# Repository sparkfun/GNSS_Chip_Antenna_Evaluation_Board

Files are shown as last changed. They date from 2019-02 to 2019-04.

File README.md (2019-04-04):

SparkFun GNSS Chip Antenna Evaluation Board
===========================================================

SparkFun GNSS Chip Antenna Eval Board (https://www.sparkfun.com/products/15247)

[*SparkFun GNSS Chip Antenna Eval Board (GPS-15247)*](https://www.sparkfun.com/products/15247)

The GNSS Chip Evaluation board allows for quick testing of various chip scale GPS and GNSS antennas. Various sizes and manufacturers allow the user to see for themselves how their GPS receiver will preform with each extremely small GPS antenna.

Repository Contents
-------------------

* **/Documents** - Antenna datasheets
* **/Hardware** - Eagle files

Documentation
-------------------

* **[Hookup Guide](https://learn.sparkfun.com/tutorials/gnss-chip-antenna-hookup-guide)** - Basic hookup guide for the antenna evaluation board
* **[Three Quick Tips About Using U.FL](https://learn.sparkfun.com/tutorials/three-quick-tips-about-using-ufl)** - Quick tips regarding how to connect, protect, and disconnect U.FL connectors

License Information
-------------------

This product is _**open source**_! 

Various bits of the code have different licenses applied. Anything SparkFun wrote is beerware; if you see me (or any other SparkFun employee) at the local, and you've found our code helpful, please buy us a round!

Please use, reuse, and modify these files as you see fit. Please maintain attribution to SparkFun Electronics and release anything derivative under the same license.

Distributed as-is; no warranty is given.

- Your friends at SparkFun.

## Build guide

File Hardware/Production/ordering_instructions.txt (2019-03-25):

panel size, 75x158mm
PCB thickness, 0.8mm
number of layers, 2
soldermask color, Red
silkscreen color, White
oz copper, 1oz
finish, HASL lead free
stencils, top+bottom
pcs per panel, 4

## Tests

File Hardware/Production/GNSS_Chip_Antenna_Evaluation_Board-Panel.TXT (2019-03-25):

%
M48
M72
T01C0.0120
T02C0.0400
T03C0.1300
%
T01
X6834Y9675
X6684Y13375
X7134Y13375
X7134Y14075
X7134Y14725
X6684Y14725
X5684Y14775
X5684Y13375
X7634Y13375
X8184Y13375
X8184Y14075
X7634Y14075
X7634Y14725
X8184Y14725
X8734Y14725
X8734Y15325
X8734Y15775
X8734Y16175
X8734Y16675
X9234Y16675
X9234Y16175
X9234Y15775
X9234Y15325
X8734Y14075
X8734Y13375
X10034Y17875
X10534Y17725
X10034Y18425
X10034Y18875
X9834Y19375
X10534Y19125
X10634Y19425
X11434Y19425
X11484Y19125
X12034Y18875
X12034Y18425
X12034Y17875
X11534Y17725
X13834Y23875
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

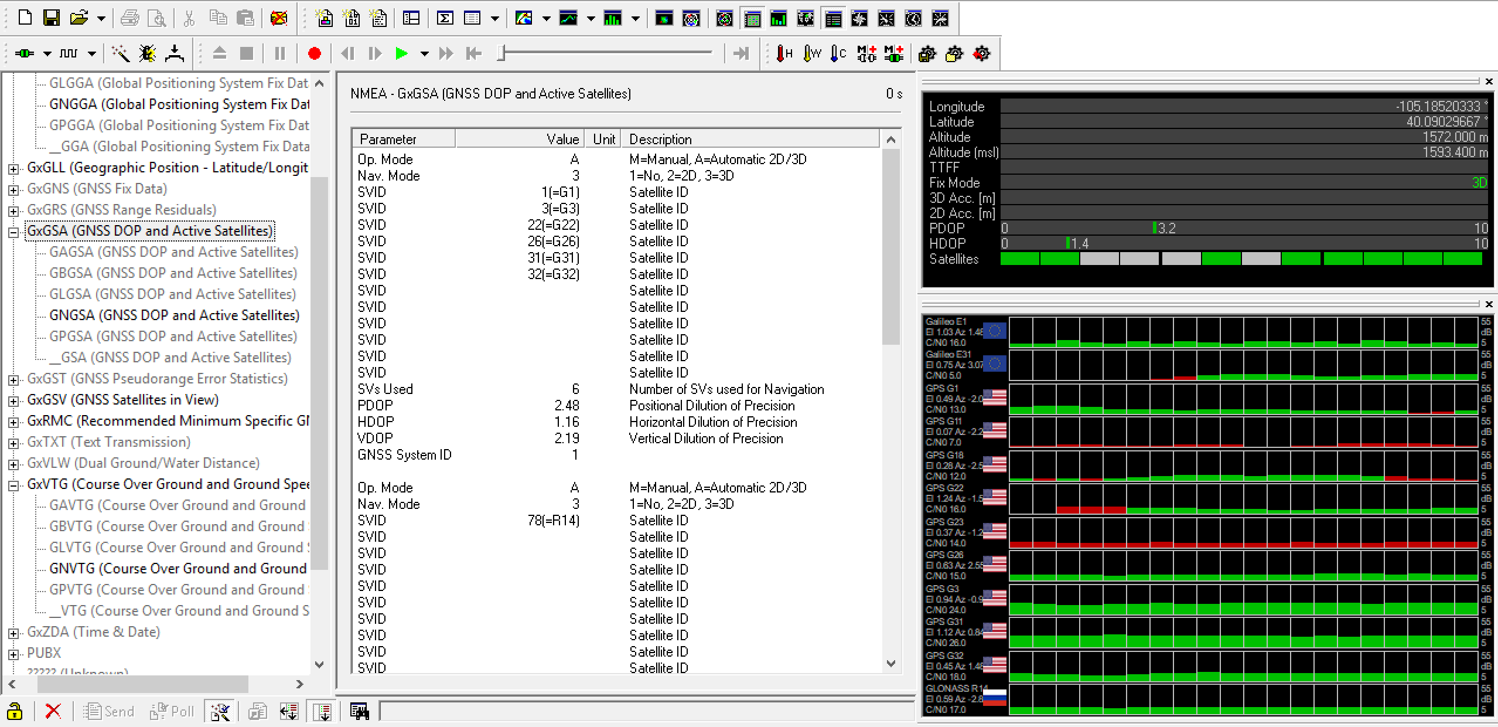
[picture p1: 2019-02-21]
Testing/W3062A.png

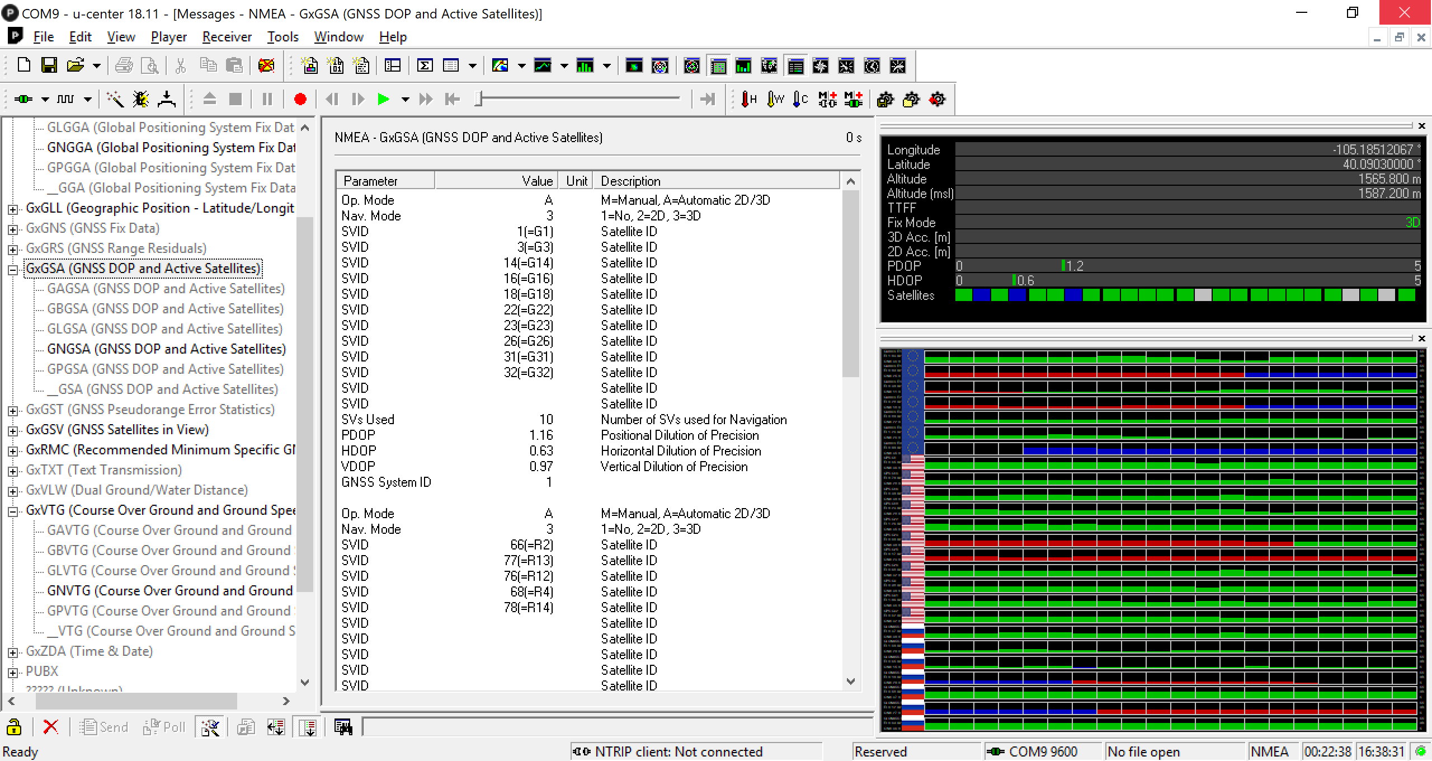
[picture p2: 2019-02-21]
Testing/Molex Cube.png

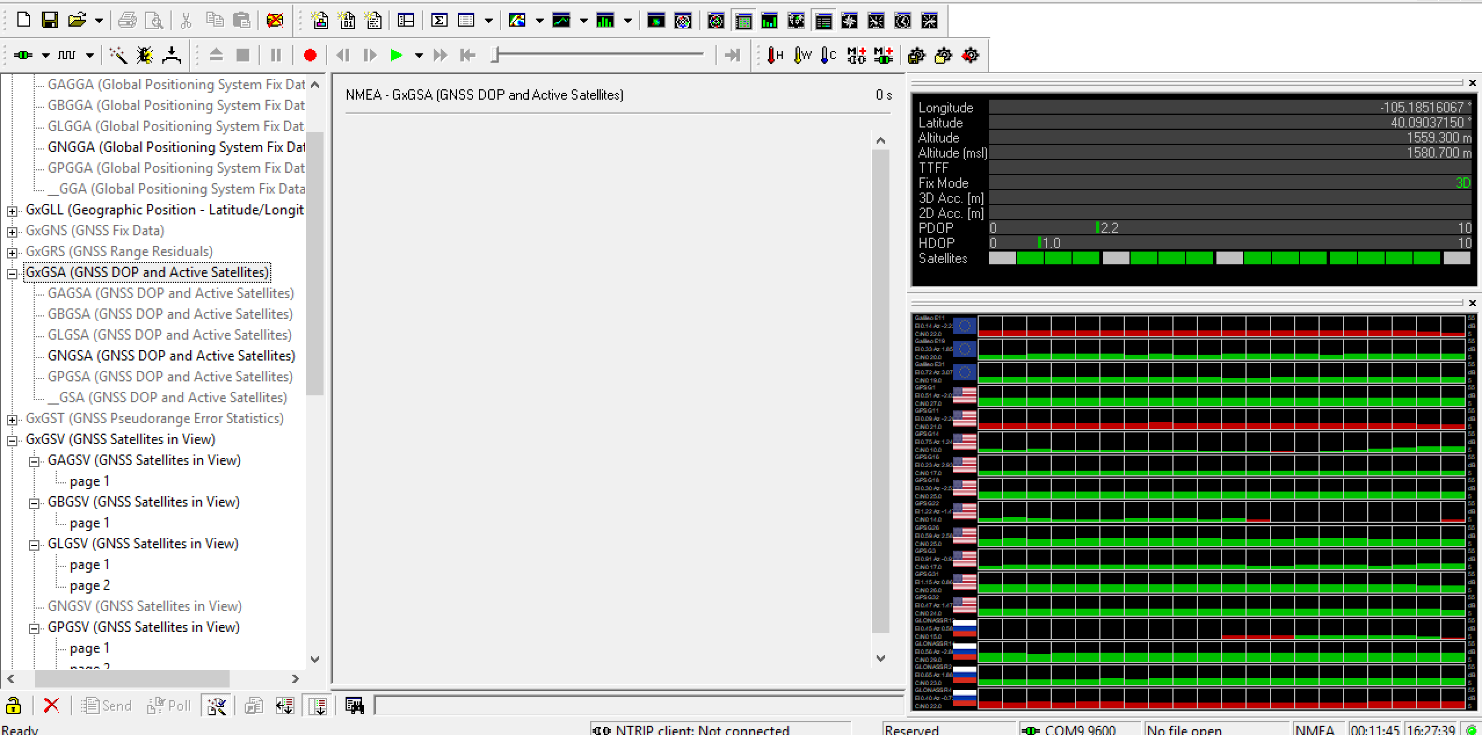
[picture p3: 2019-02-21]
Testing/Molex Molded.png

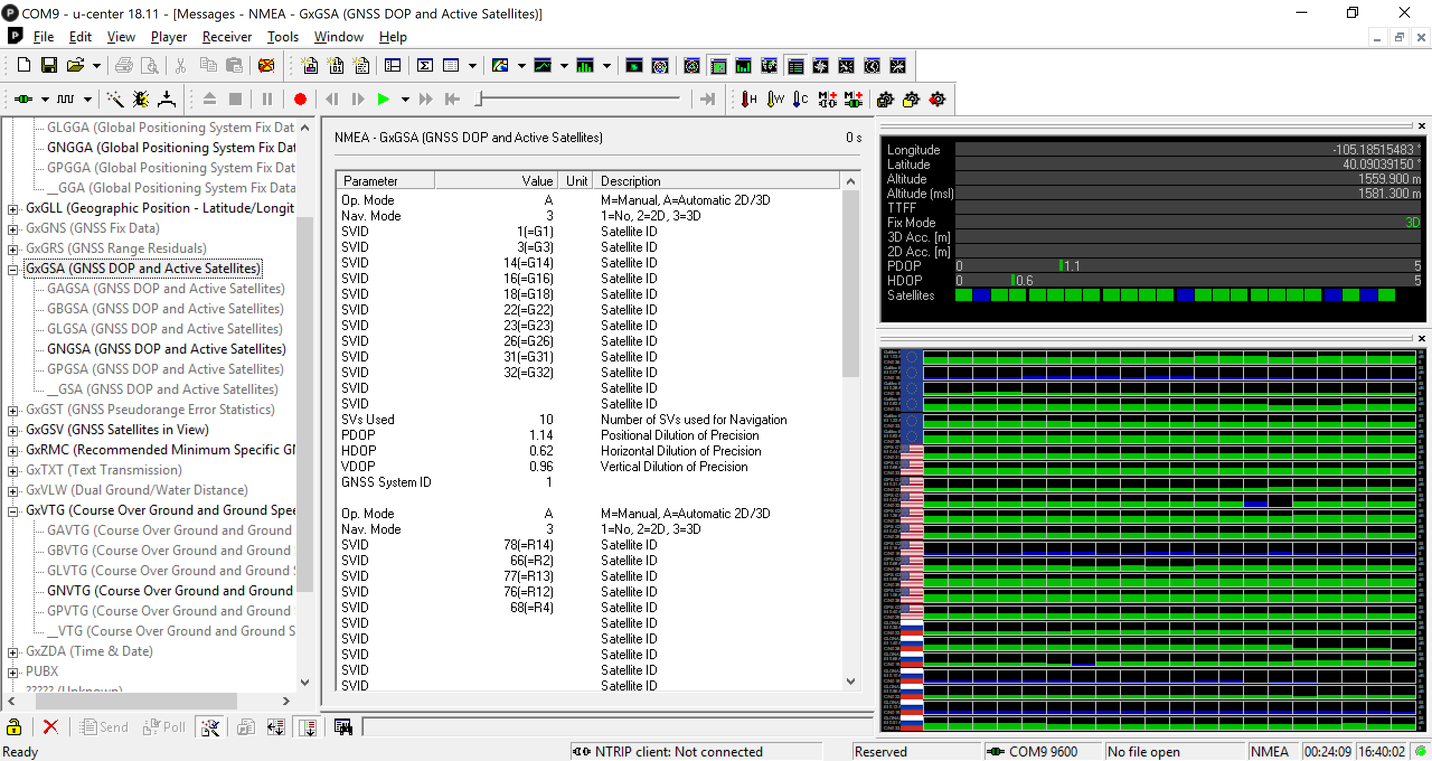
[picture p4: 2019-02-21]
Testing/Adhesive Ant.png

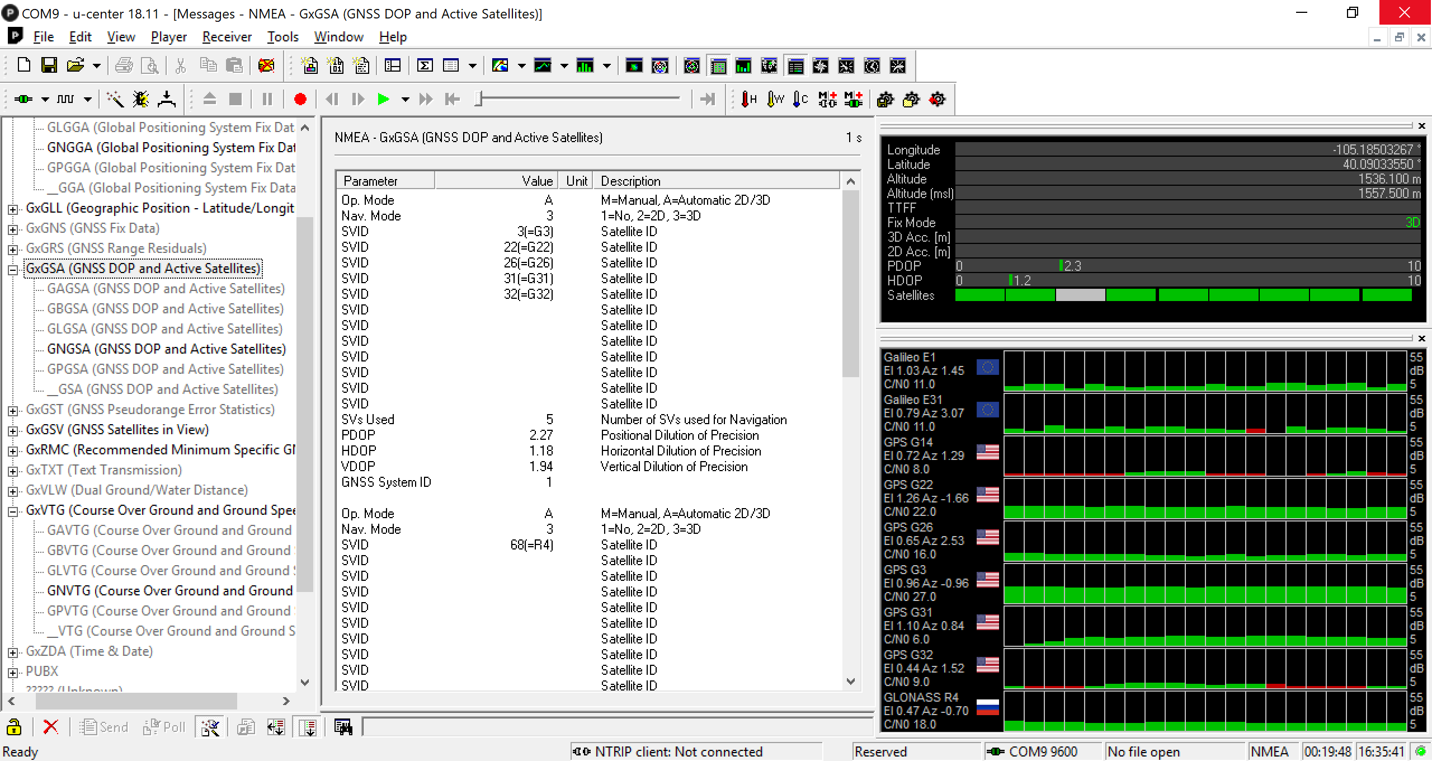
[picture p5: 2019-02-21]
Testing/Molex Chip.png

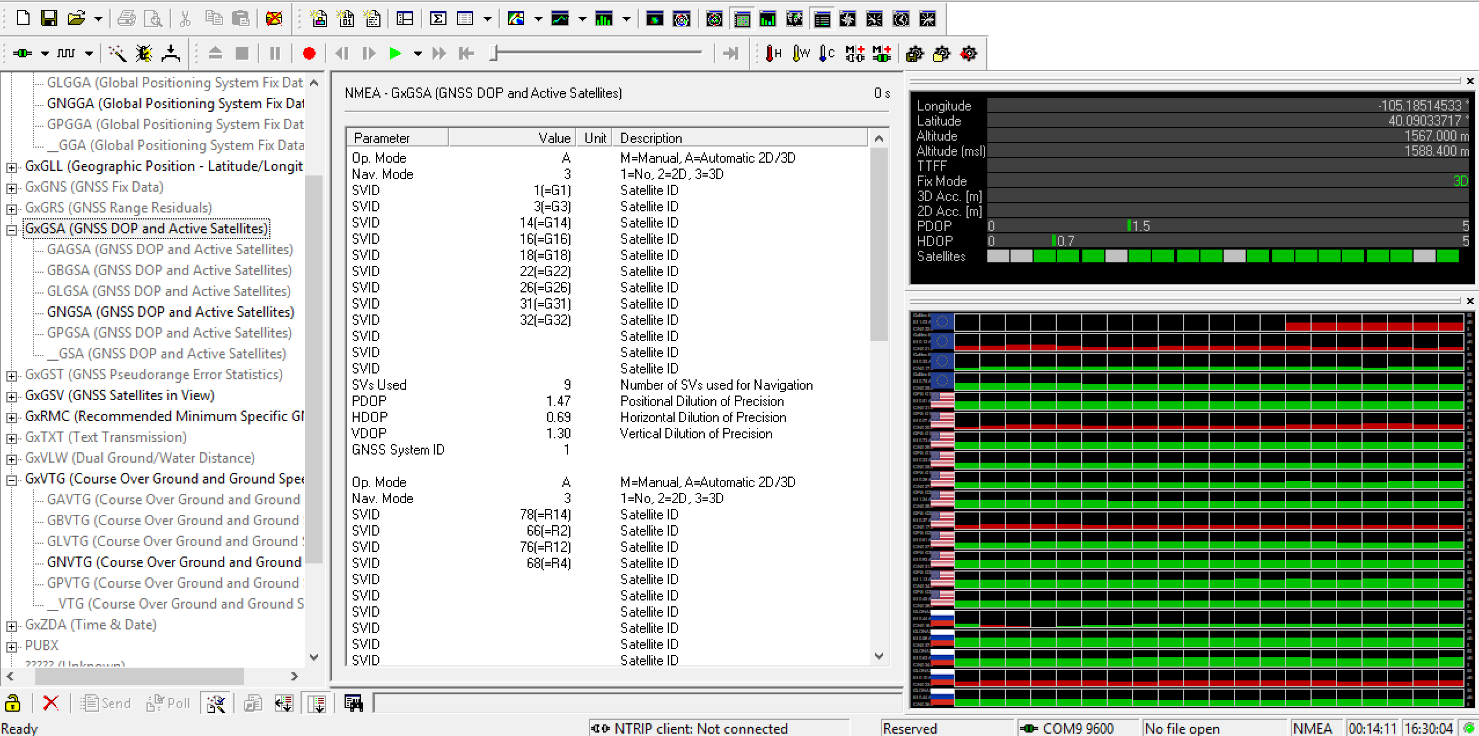
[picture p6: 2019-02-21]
Testing/W3011.png

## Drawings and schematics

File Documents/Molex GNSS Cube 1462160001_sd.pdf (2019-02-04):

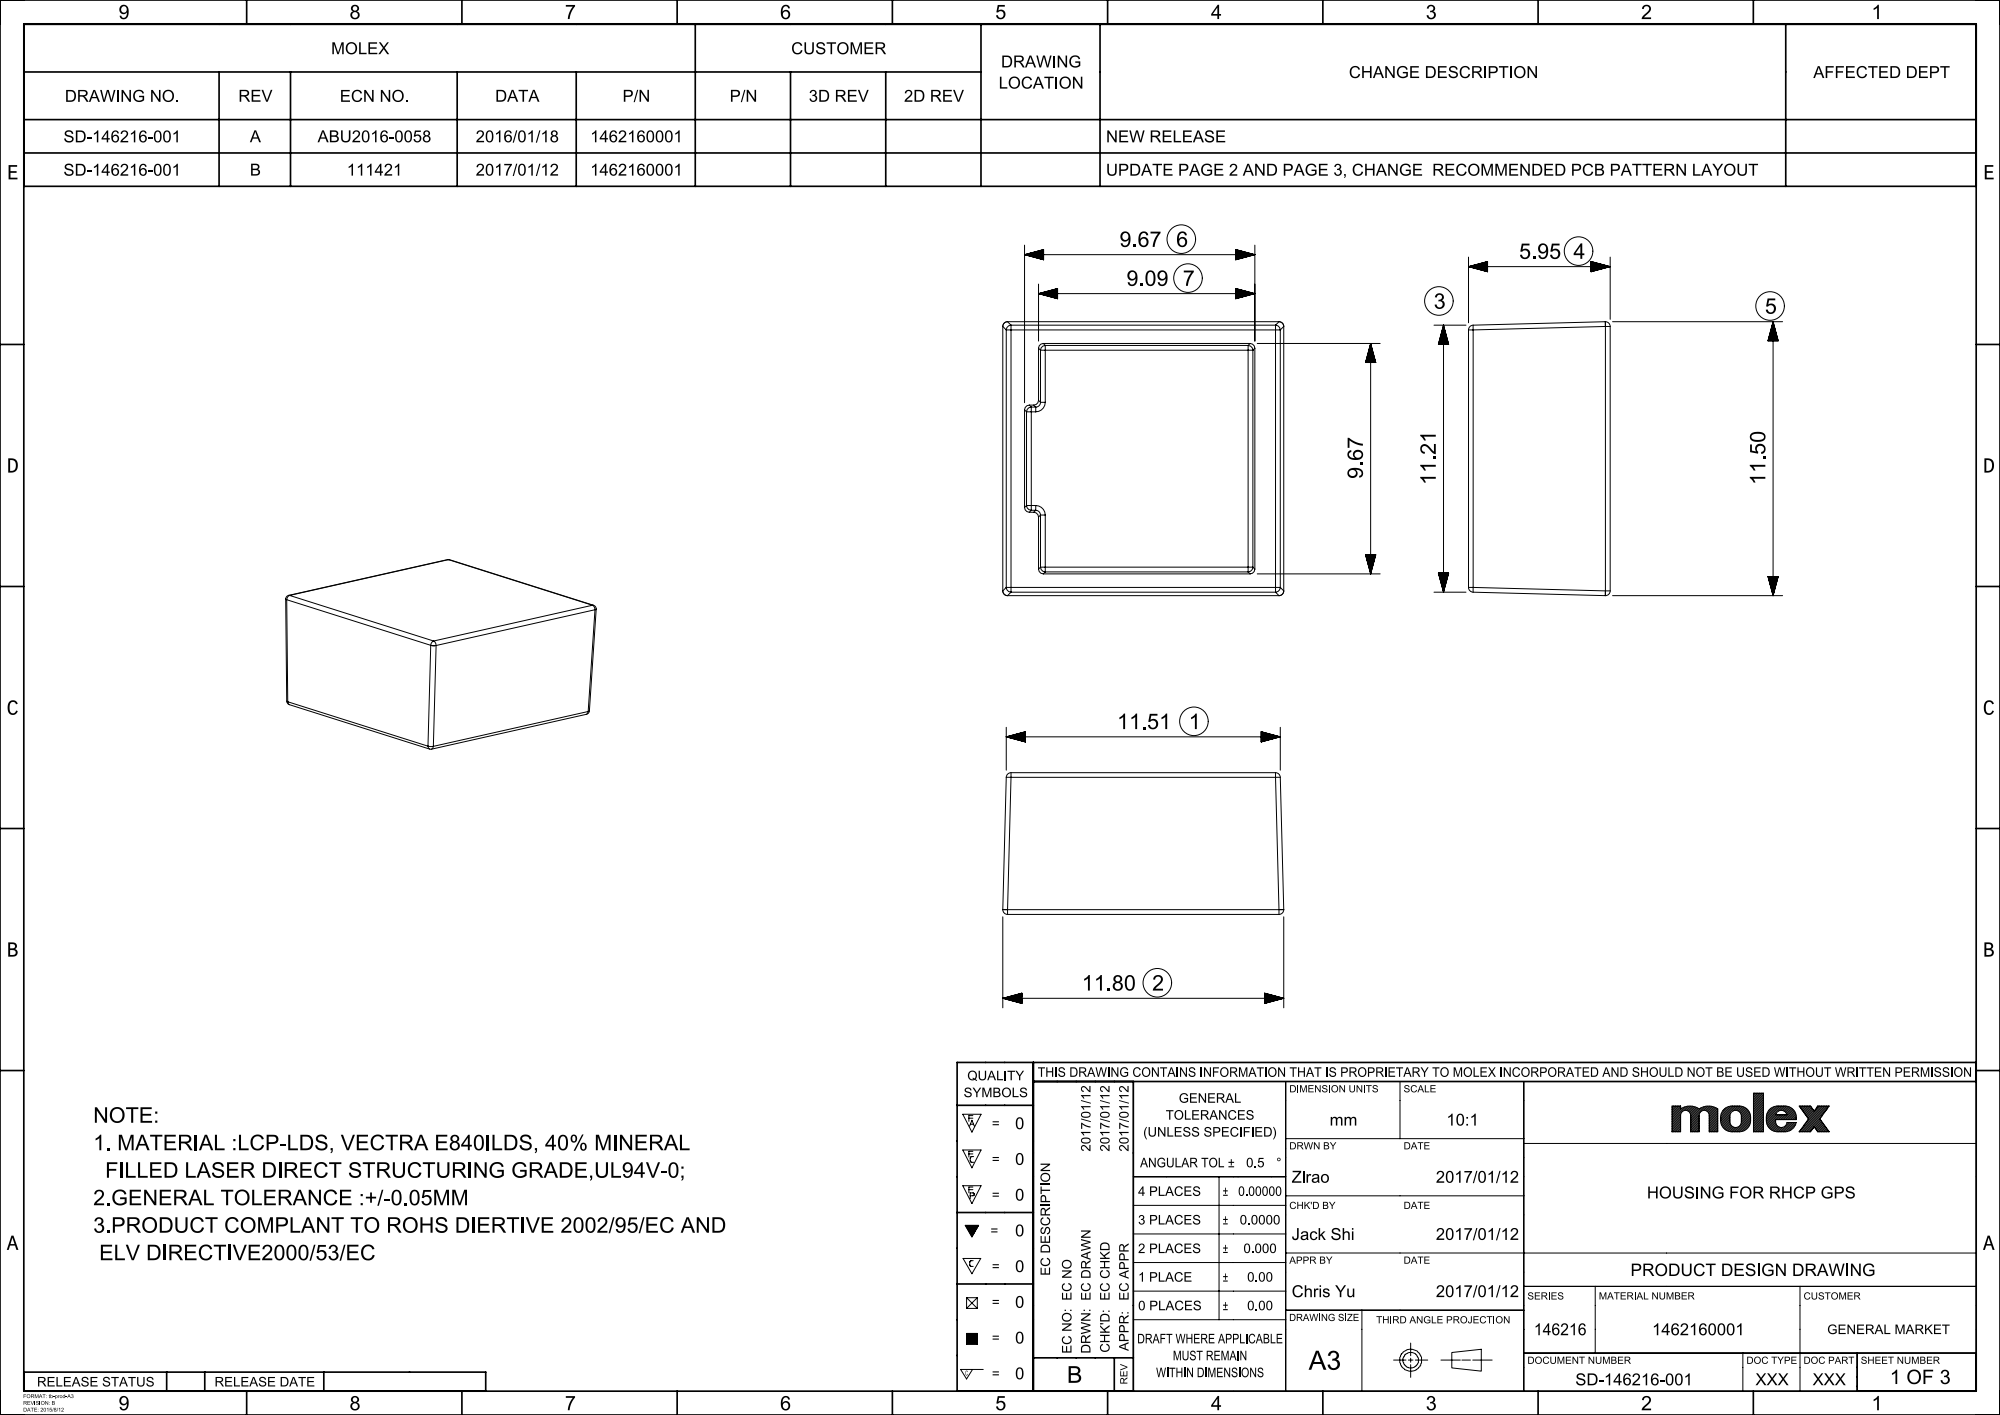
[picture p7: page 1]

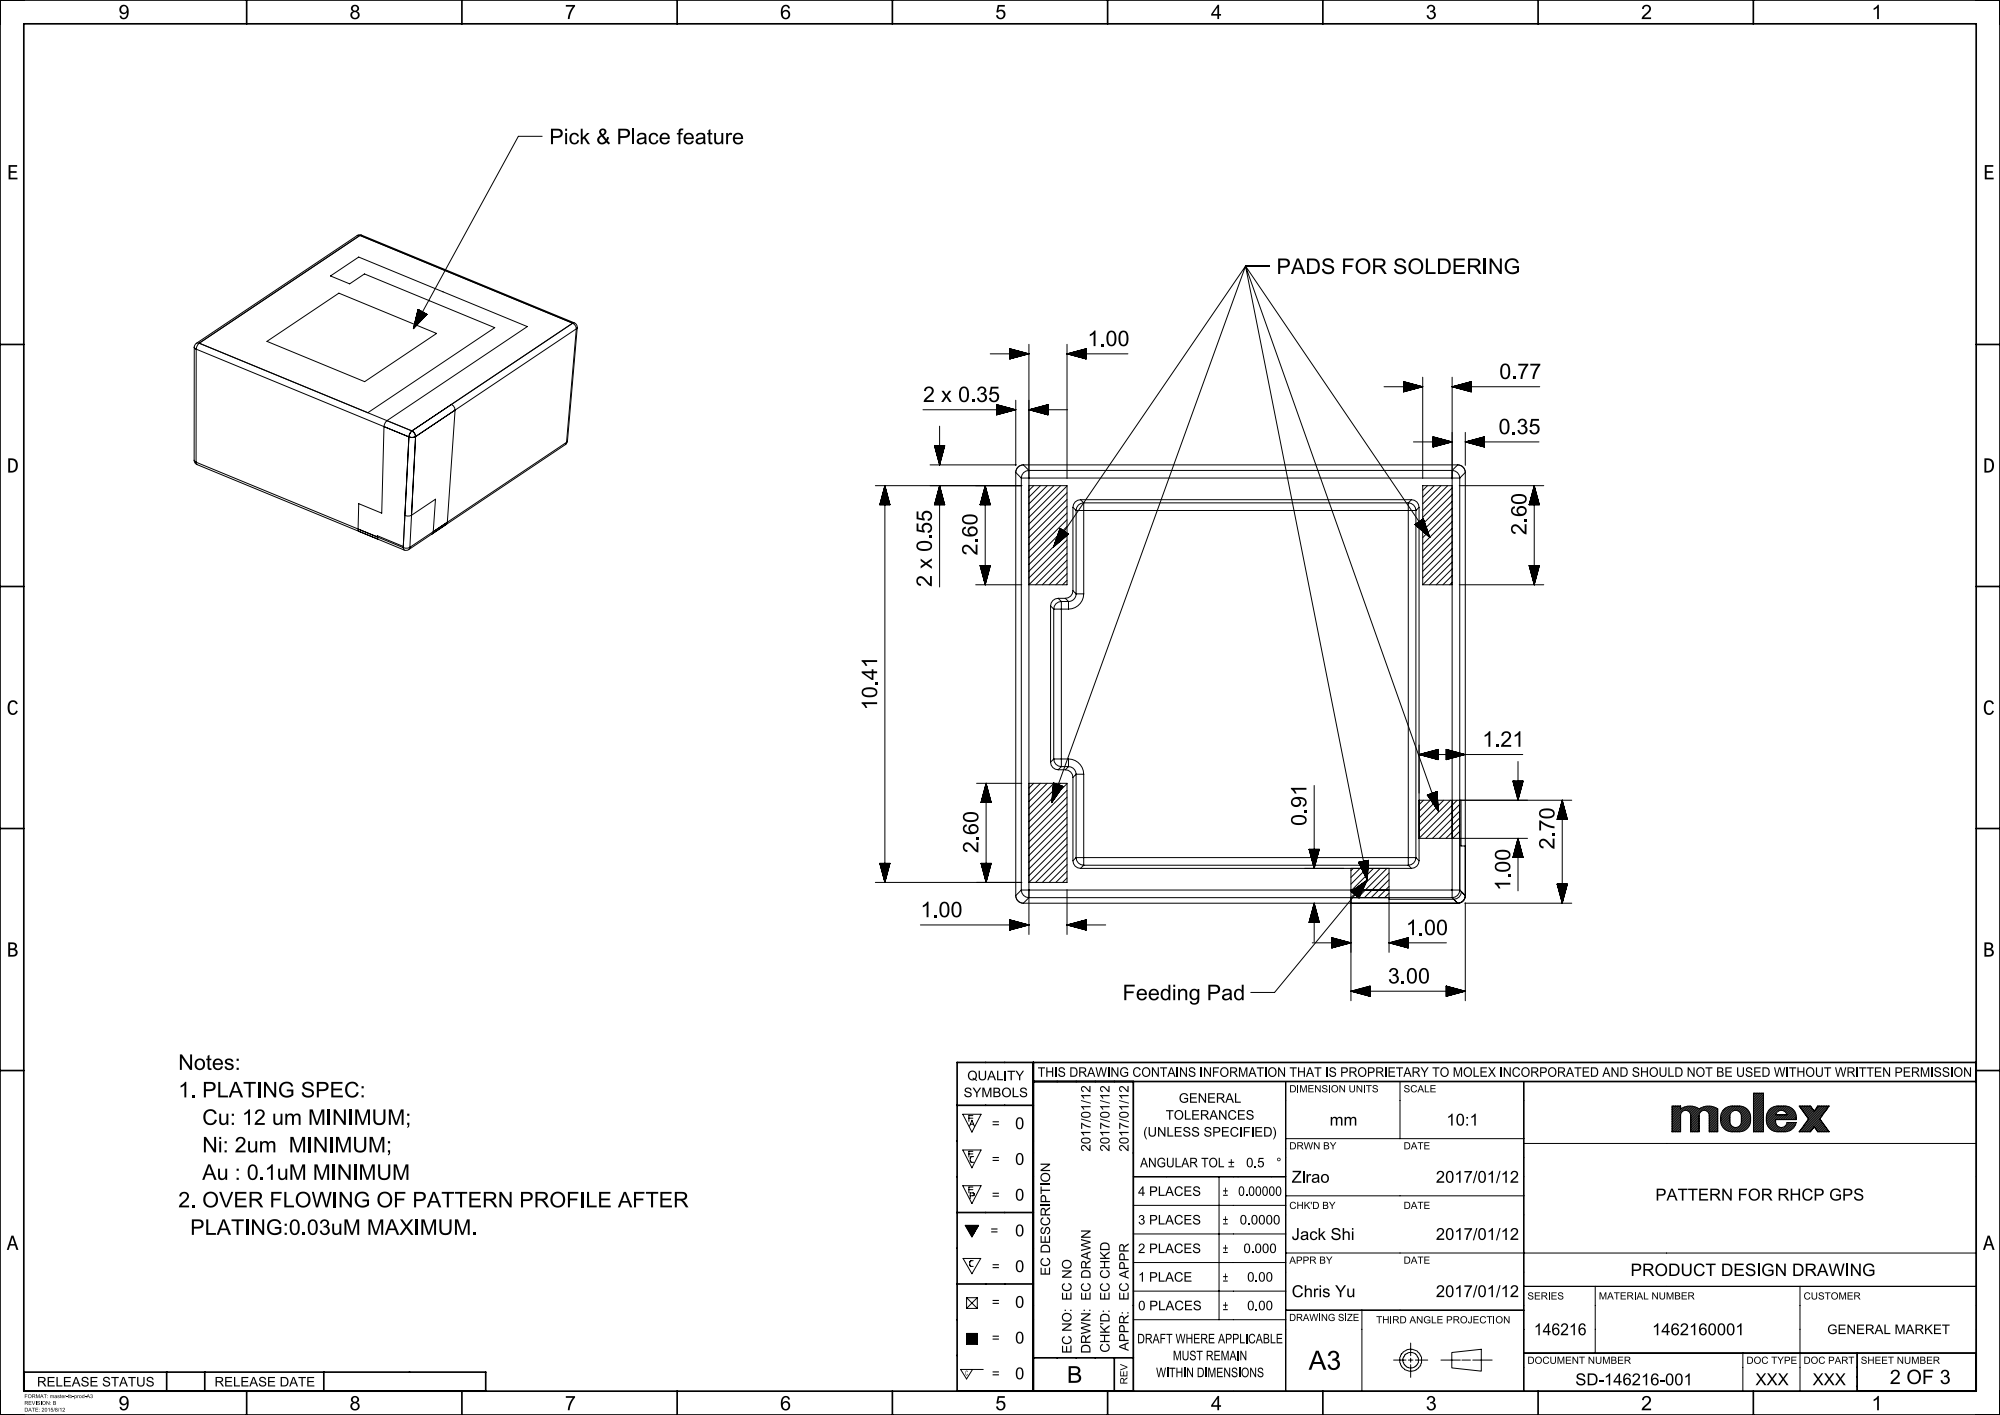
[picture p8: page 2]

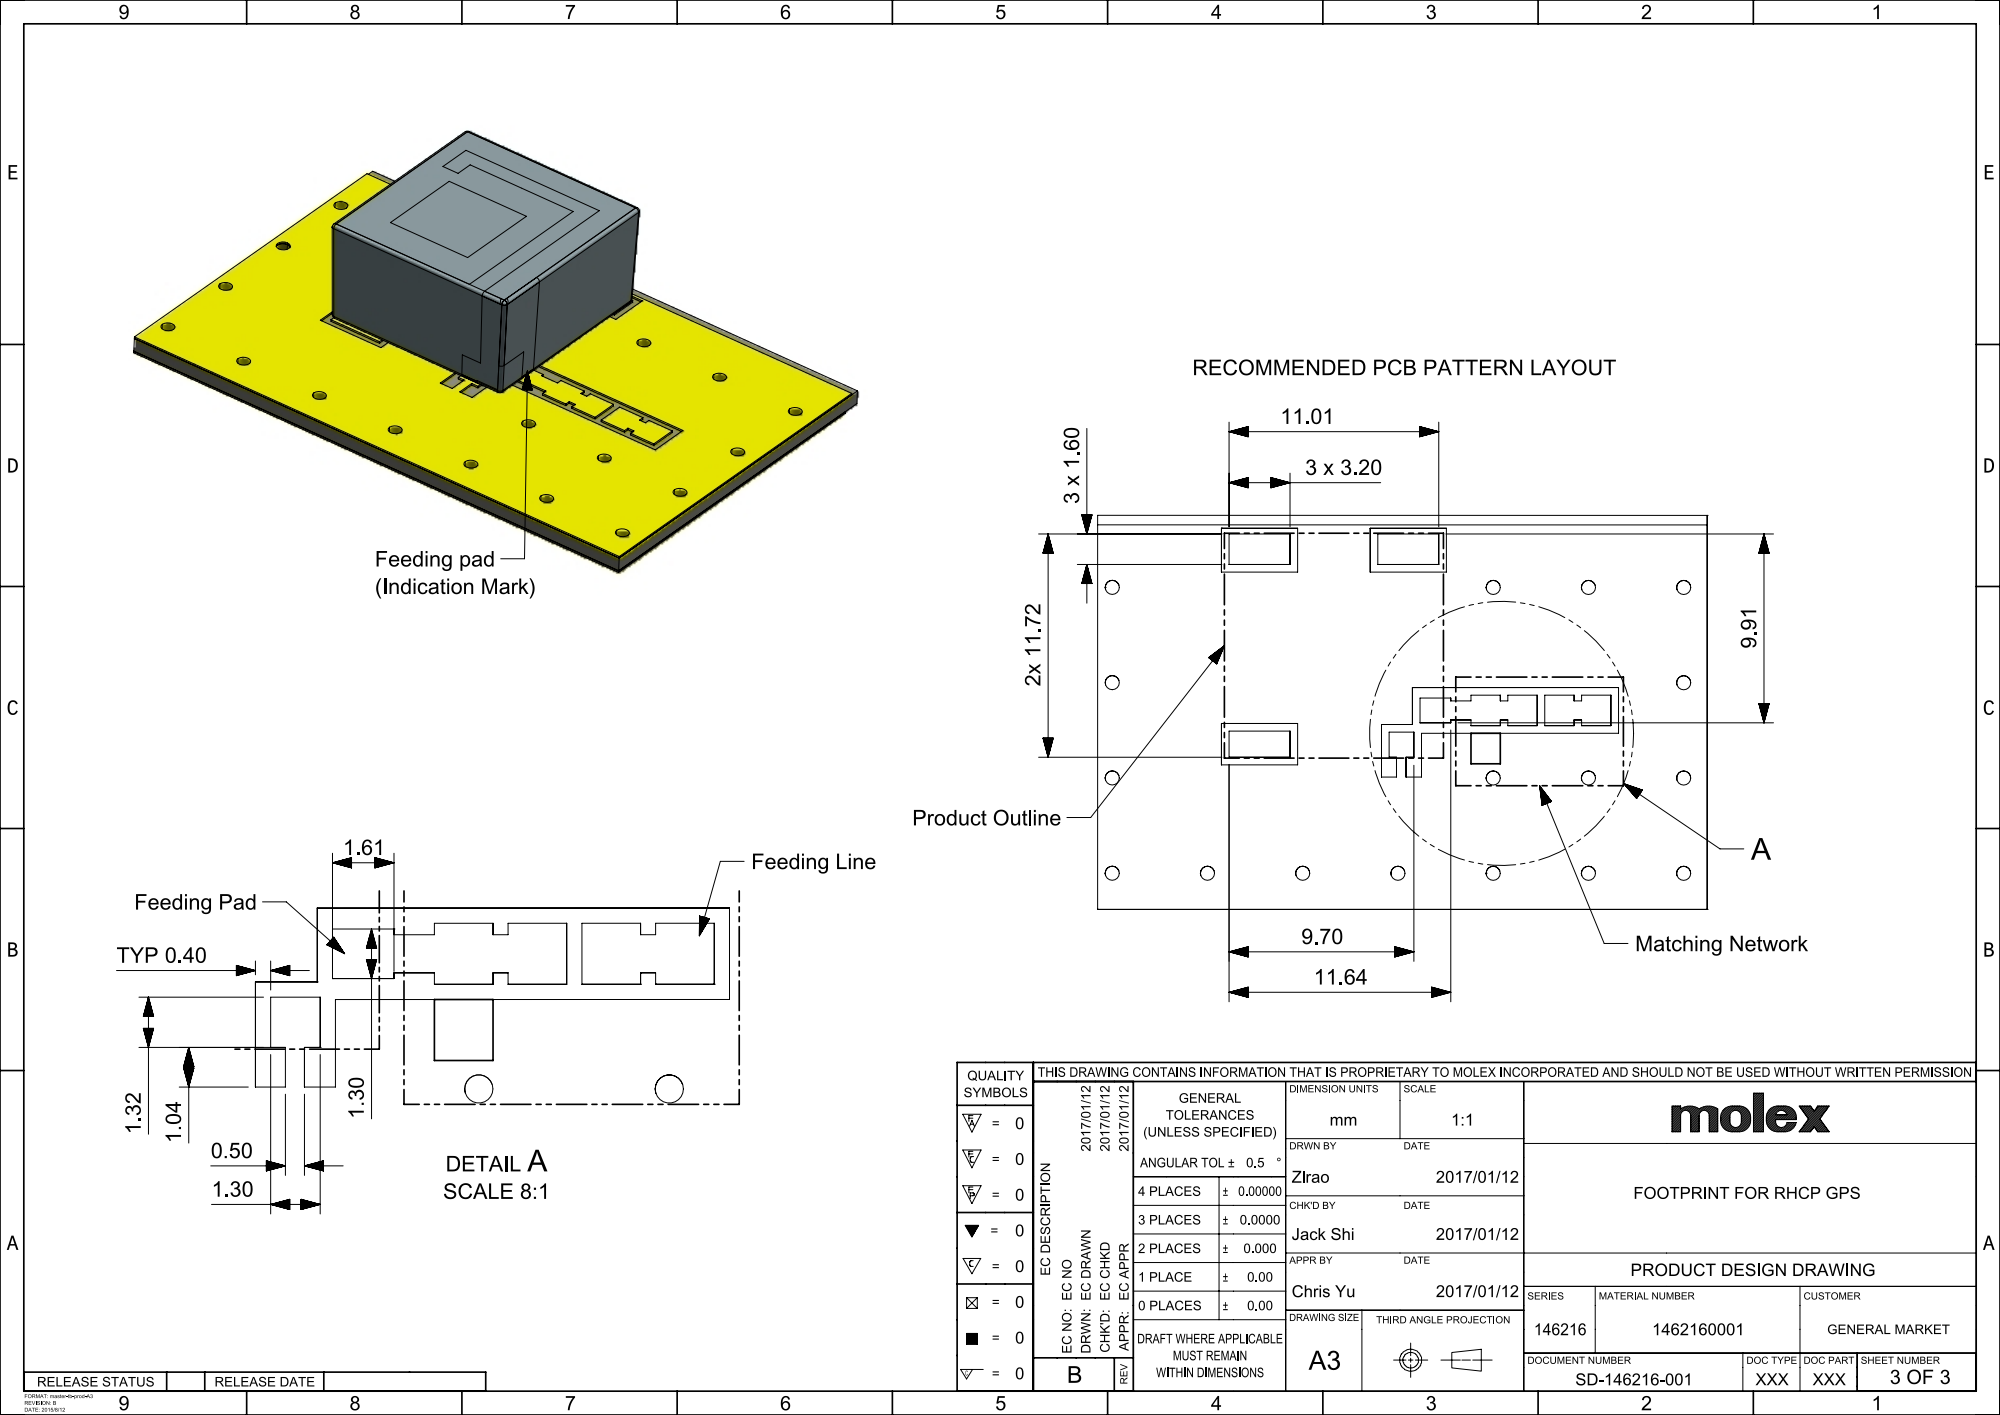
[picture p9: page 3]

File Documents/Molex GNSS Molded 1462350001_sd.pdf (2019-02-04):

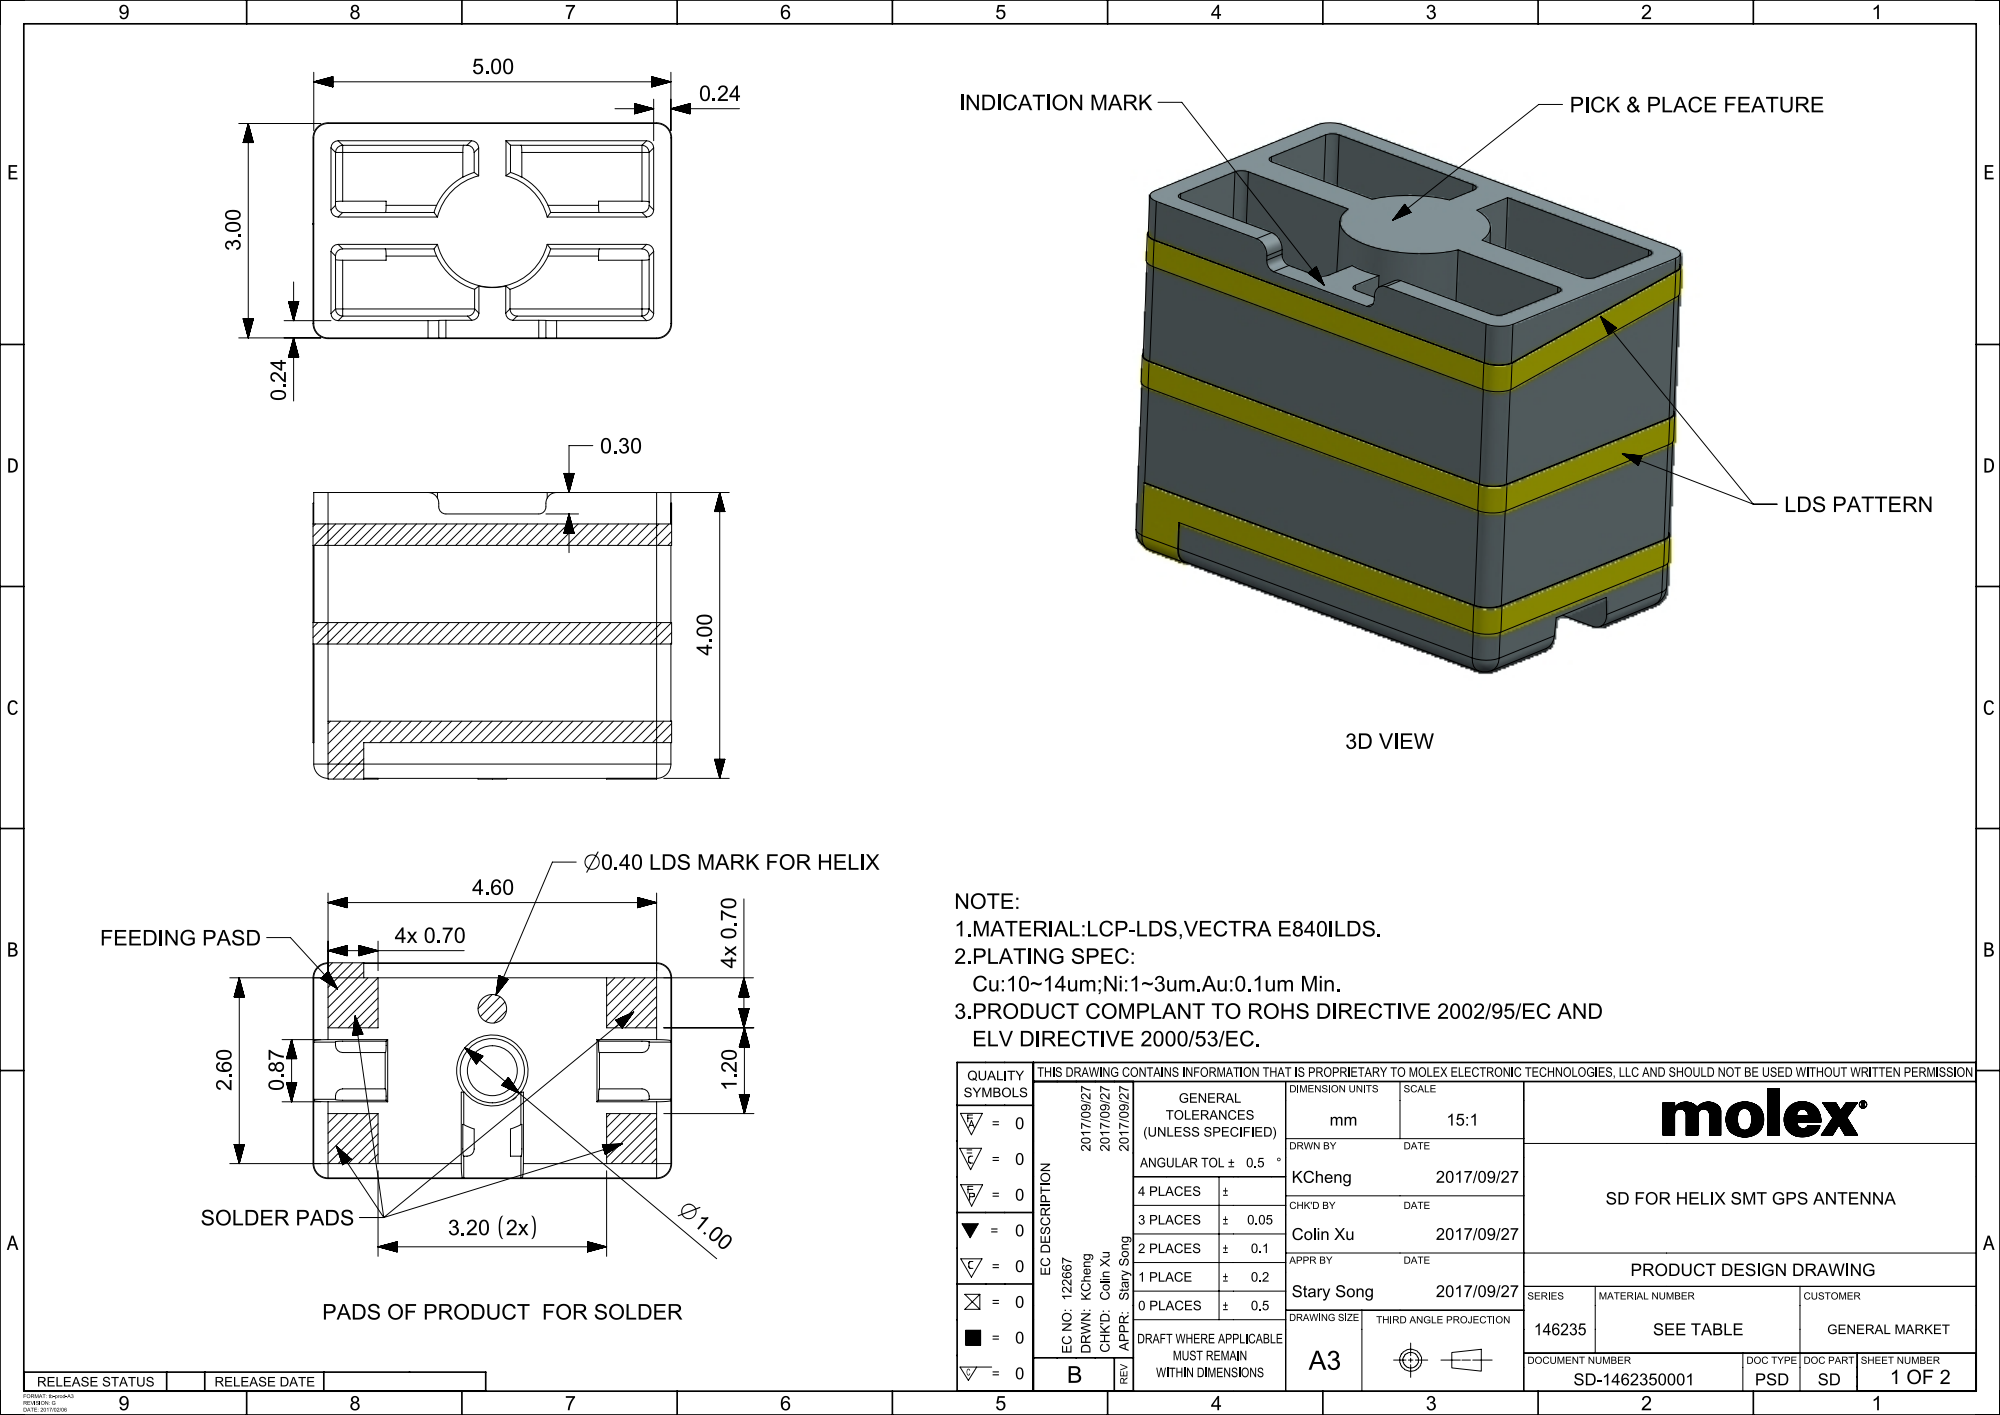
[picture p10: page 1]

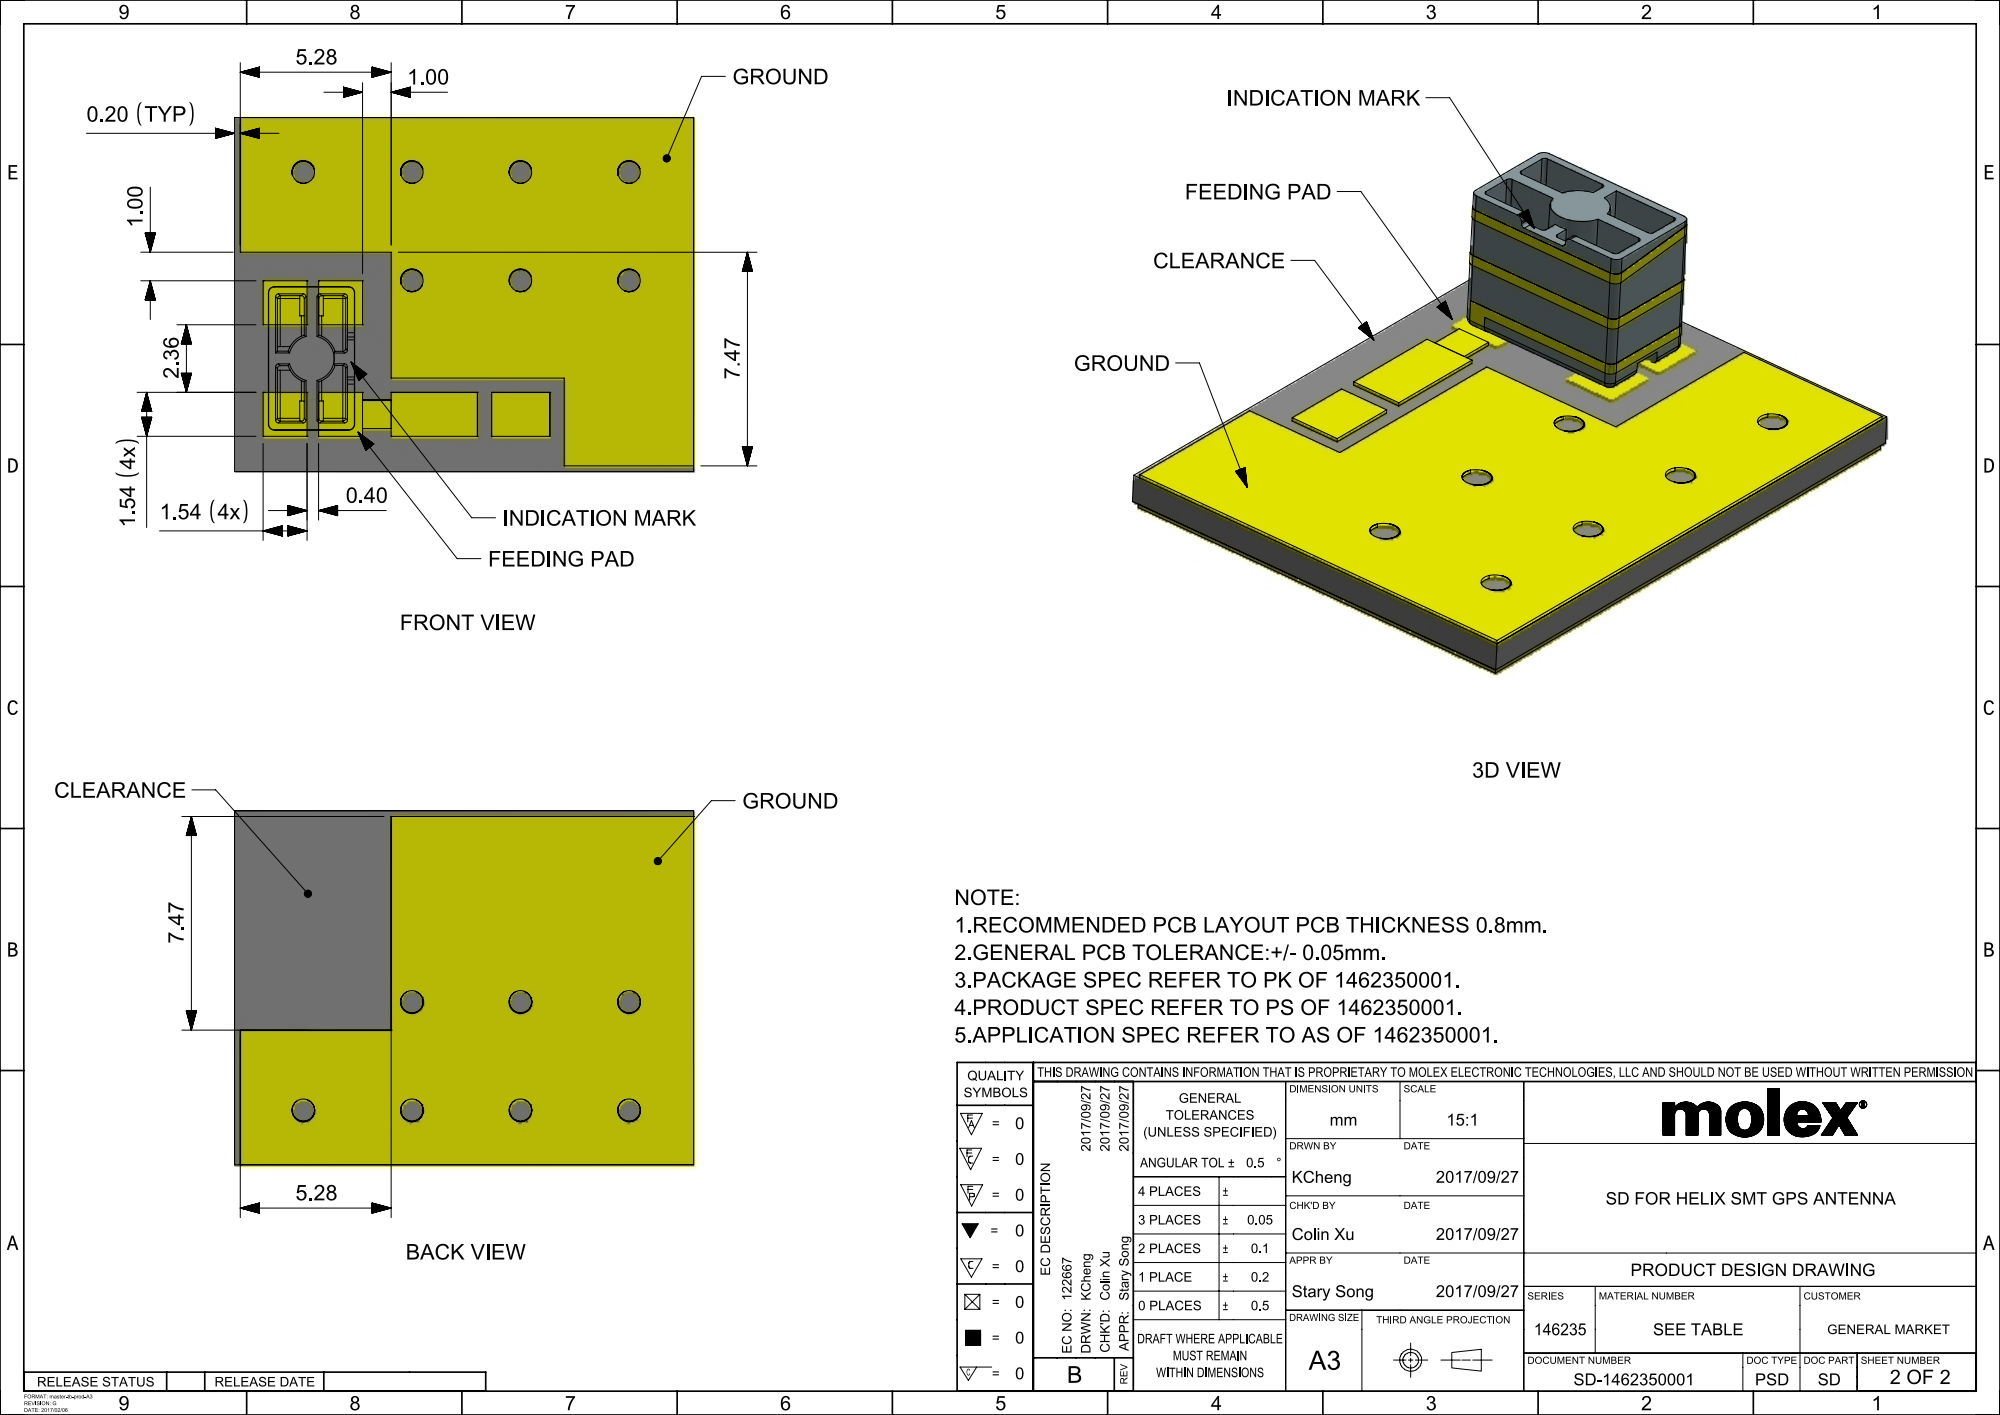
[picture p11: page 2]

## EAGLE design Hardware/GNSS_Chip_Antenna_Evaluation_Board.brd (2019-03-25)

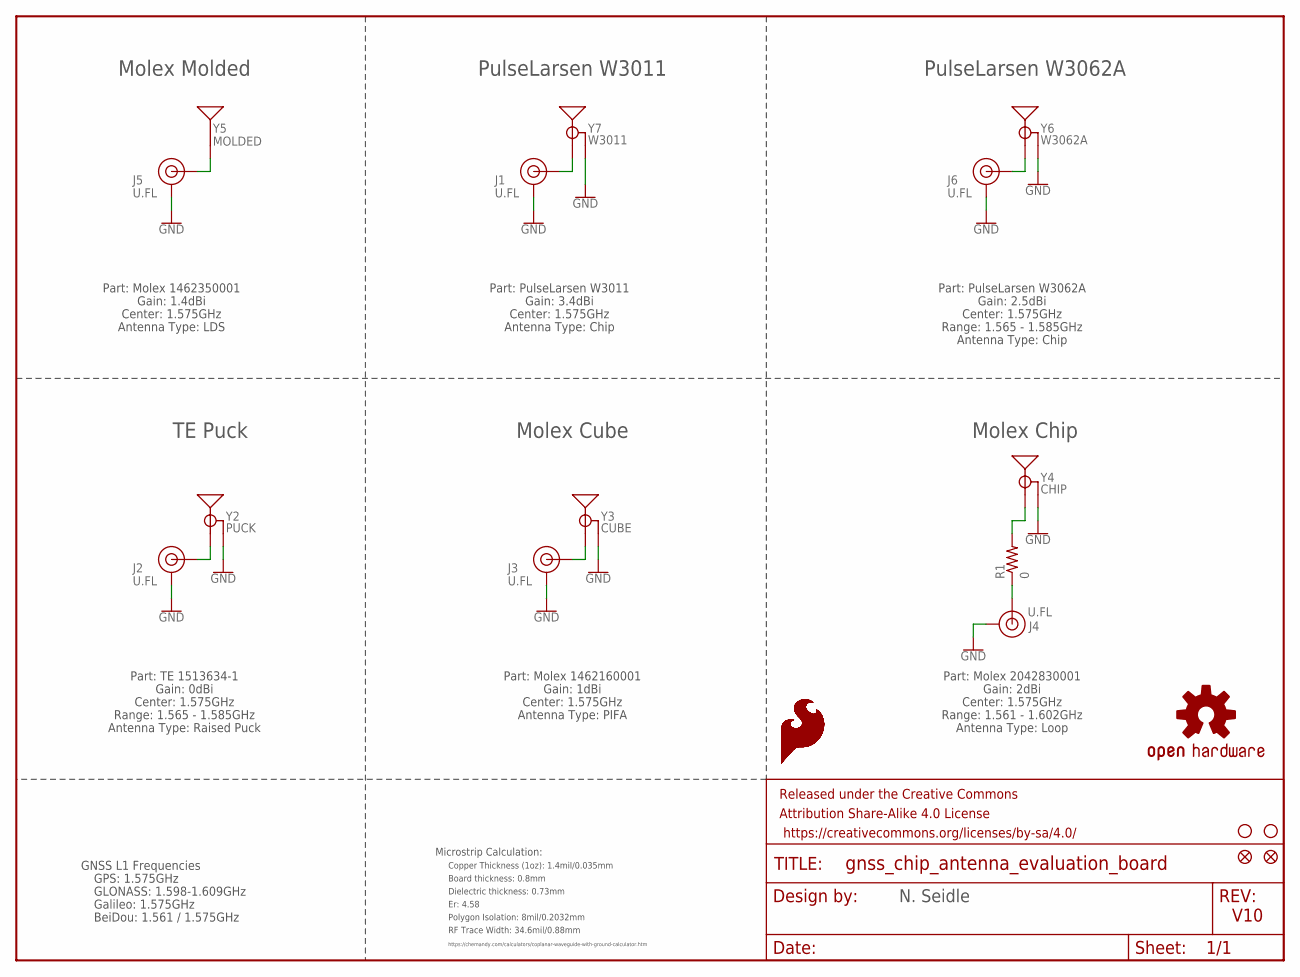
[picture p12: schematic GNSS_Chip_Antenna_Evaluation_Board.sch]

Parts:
FRAME1: FRAME-LETTER; CREATIVE_COMMONS
J1, J2, J3, J4, J5, J6: U.FL
JP5, JP6: STAND-OFF
JP8, JP9: FIDUCIAL1X2; FIDUCIAL-1X2
LOGO1, LOGO2, LOGO3, LOGO4, LOGO5, LOGO6: SFE_LOGO_FLAME.1EXP; SFE_LOGO_FLAME_COPPER_EXPOSED_.1
R1: 0; 0402
U$16: OSHW-LOGOS; OSHW-LOGO-S
Y2: PUCK; TE_PUCK
Y3: CUBE; MOLEX_GNSS_CUBE
Y4: CHIP; MOLEX_GNSS_CHIP
Y5: MOLDED; MLOEX_GNSS_MOLDED
Y6: W3062A
Y7: W3011

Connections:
FEED1: J1.FEED (SIGNAL), Y7.1 (SIGNAL)
FEED2: J5.FEED (SIGNAL), Y5.FEED
FEED3: J2.FEED (SIGNAL), Y2.S (SIGNAL)
FEED4: J3.FEED (SIGNAL), Y3.FEED (SIGNAL)
FEED5: J4.FEED (SIGNAL), R1.1
FEED6: J6.FEED (SIGNAL), Y6.FEED (SIGNAL)
GND: J1.1 (GND), J1.2 (GND), J2.1 (GND), J2.2 (GND), J3.1 (GND), J3.2 (GND), J4.1 (GND), J4.2 (GND), J5.1 (GND), J5.2 (GND), J6.1 (GND), J6.2 (GND), Y2.1 (GND), Y2.2 (GND), Y2.3 (GND), Y3.GND, Y4.1 (GND), Y4.2 (GND), Y4.3 (GND), Y6.GND, Y7.2 (GND), Y7.3 (GND)
unnamed: R1.2, Y4.FEED (SIGNAL)

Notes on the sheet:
V10
Board thickness: 0.8mm
Er: 4.58
Copper Thickness (1oz): 1.4mil/0.035mm
RF Trace Width: 34.6mil/0.88mm
Polygon Isolation: 8mil/0.2032mm
Dielectric thickness: 0.73mm
https://chemandy.com/calculators/coplanar-waveguide-with-ground-calculator.htm
Microstrip Calculation:
Center: 1.575GHz
Gain: 1.4dBi
Part: Molex 1462350001
Range: 1.565 - 1.585GHz
Gain: 2.5dBi
Part: PulseLarsen W3062A
Gain: 3.4dBi
Part: PulseLarsen W3011
Gain: 1dBi
Part: Molex 1462160001
Gain: 0dBi
Part: TE 1513634-1
Range: 1.561 - 1.602GHz
Gain: 2dBi
Part: Molex 2042830001
Antenna Type: Chip
Antenna Type: Loop
Antenna Type: PIFA
Antenna Type: Raised Puck
Antenna Type: LDS
GPS: 1.575GHz
GLONASS: 1.598-1.609GHz
Galileo: 1.575GHz
BeiDou: 1.561 / 1.575GHz
Molex Molded
Molex Chip
Molex Cube
PulseLarsen W3062A
PulseLarsen W3011
TE Puck
N. Seidle

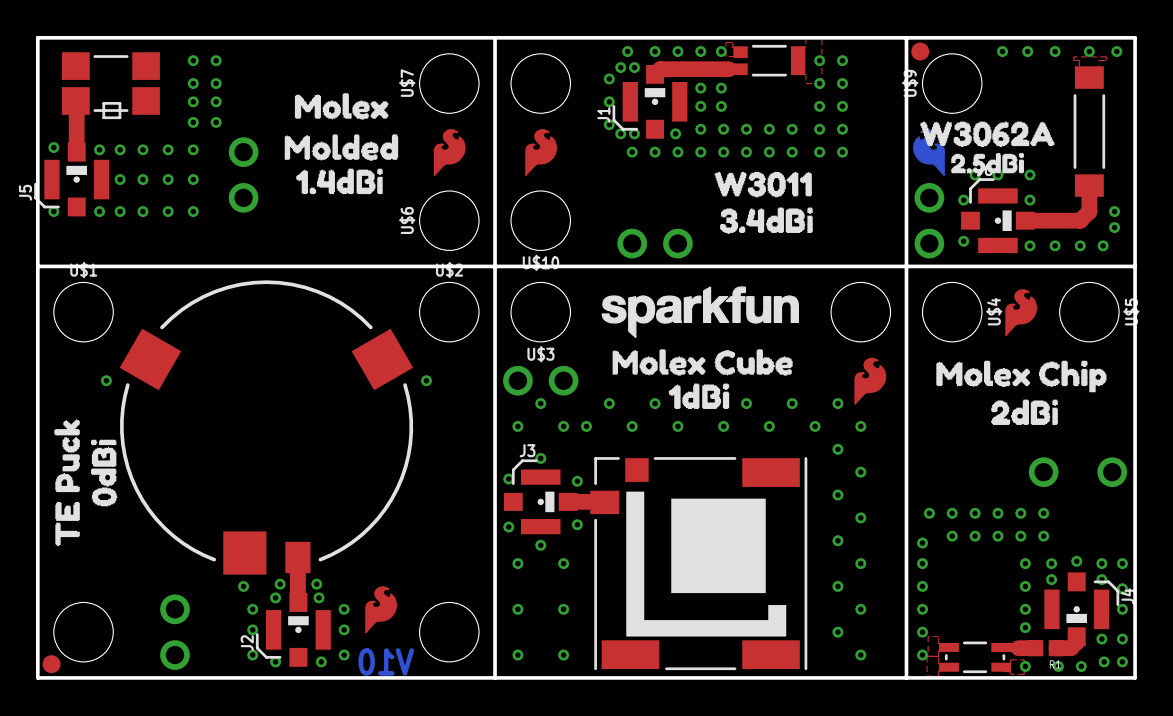
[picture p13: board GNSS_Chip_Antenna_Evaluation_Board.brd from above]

Board: 2 copper layers, 61.0 x 35.6 mm, 74 parts (25 on the bottom side), 8 nets.

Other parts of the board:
JP1, JP2: STAND-OFF
U$1, U$2, U$3, U$4, U$5, U$6, U$7, U$9, U$10: STAND-OFF
U$8, U$24, U$25, U$26, U$27, U$28: ANCHOR0
U$11, U$34: 3#4DBI2
U$12, U$42: 0DBI0
U$13, U$57: TE_PUCK7
U$14, U$32: 1#4DBI3
U$15, U$39: 1DBI1
U$17: ORDERING_INSTRUCTIONS
U$18, U$38: 2DBI2
U$19, U$20: MOLEX_CHIP5
U$21, U$22: MOLEX0
U$23: SFE_LOGO_NAME_.1
U$29, U$30: MOLDED1
U$31, U$56: MOLEX_CUBE6
U$33, U$59: W30112
U$35, U$58: W3062A3
U$36: 2#5DBI4
U$37: SFE_LOGO_NAME_FLAME_.1
U$43: ANTENNA10
U$44: 2#5DBI2
U$50: EVALUATION_BOARD15
U$52: GNSS_CHIP13

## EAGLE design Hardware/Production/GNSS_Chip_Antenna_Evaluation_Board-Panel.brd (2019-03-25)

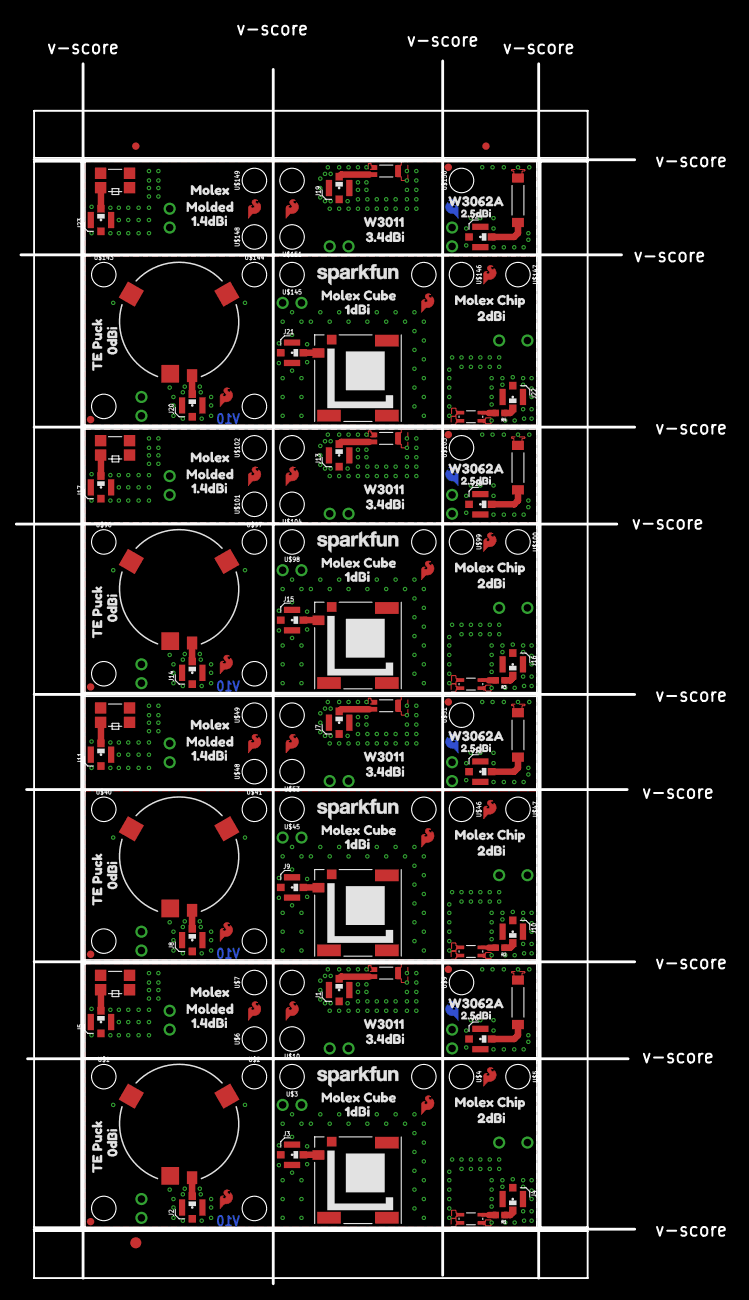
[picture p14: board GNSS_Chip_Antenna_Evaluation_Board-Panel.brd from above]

Board: 2 copper layers, 83.4 x 165.0 mm, 291 parts (100 on the bottom side), 32 nets.

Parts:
E$1, E$2: FIDUCIAL-1X2
E$3: FIDUCIAL-1.5X3
J1, J2, J3, J4, J5, J6, J7, J8, J9, J10, J11, J12, J13, J14, J15, J16, J17, J18, J19, J20, J21, J22, J23, J24: U.FL
JP1, JP2, JP3, JP4, JP5, JP6, JP11, JP12, JP13, JP14, JP17, JP18, JP19, JP20, JP23, JP24: STAND-OFF
JP7, JP8, JP9, JP10, JP15, JP16, JP21, JP22: FIDUCIAL1X2; FIDUCIAL-1X2
LOGO1, LOGO2, LOGO3, LOGO4, LOGO5, LOGO6, LOGO7, LOGO8, LOGO9, LOGO10, LOGO11, LOGO12, LOGO13, LOGO14, LOGO15, LOGO16, LOGO17, LOGO18, LOGO19, LOGO20, LOGO21, LOGO22, LOGO23, LOGO24: SFE_LOGO_FLAME.1EXP; SFE_LOGO_FLAME_COPPER_EXPOSED_.1
R1, R2, R3, R4: 0; 0402
U$1, U$2, U$3, U$4, U$5, U$6, U$7, U$9, U$10, U$40, U$41, U$45, U$46, U$47, U$48, U$49, U$51, U$53, U$96, U$97, U$98, U$99, U$100, U$101, U$102, U$103, U$104, U$143, U$144, U$145, U$146, U$147, U$148, U$149, U$150, U$151: STAND-OFF
U$8, U$24, U$25, U$26, U$27, U$28, U$63, U$64, U$65, U$66, U$67, U$68, U$110, U$111, U$112, U$113, U$114, U$115, U$157, U$158, U$159, U$160, U$161, U$162: ANCHOR0
U$11, U$34, U$54, U$70, U$105, U$117, U$152, U$164: 3#4DBI2
U$12, U$42, U$55, U$74, U$106, U$121, U$153, U$168: 0DBI0
U$13, U$57, U$81, U$84, U$128, U$131, U$175, U$178: TE_PUCK7
U$14, U$32, U$60, U$69, U$107, U$116, U$154, U$163: 1#4DBI3
U$15, U$39, U$61, U$73, U$108, U$120, U$155, U$167: 1DBI1
U$16, U$17, U$95, U$142: OSHW-LOGOS; OSHW-LOGO-S
U$18, U$38, U$62, U$72, U$109, U$119, U$156, U$166: 2DBI2
U$19, U$20, U$85, U$86, U$132, U$133, U$179, U$180: MOLEX_CHIP5
U$21, U$22, U$87, U$89, U$134, U$136, U$181, U$183: MOLEX0
U$23, U$76, U$123, U$170: SFE_LOGO_NAME_.1
U$29, U$30, U$88, U$90, U$135, U$137, U$182, U$184: MOLDED1
U$31, U$56, U$80, U$91, U$127, U$138, U$174, U$185: MOLEX_CUBE6
U$33, U$59, U$83, U$92, U$130, U$139, U$177, U$186: W30112
U$35, U$58, U$82, U$93, U$129, U$140, U$176, U$187: W3062A3
U$36, U$71, U$118, U$165: 2#5DBI4
U$37, U$94, U$141, U$188: SFE_LOGO_NAME_FLAME_.1
U$43, U$77, U$124, U$171: ANTENNA10
U$44, U$75, U$122, U$169: 2#5DBI2
U$50, U$78, U$125, U$172: EVALUATION_BOARD15
U$52, U$79, U$126, U$173: GNSS_CHIP13
Y1, Y2, Y13, Y19: PUCK; TE_PUCK
Y3, Y8, Y14, Y20: CUBE; MOLEX_GNSS_CUBE
Y4, Y9, Y15, Y21: CHIP; MOLEX_GNSS_CHIP
Y5, Y10, Y16, Y22: MOLDED; MLOEX_GNSS_MOLDED
Y6, Y11, Y17, Y23: W3062A
Y7, Y12, Y18, Y24: W3011

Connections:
FEED1: J1.FEED, Y7.1
FEED2: J5.FEED, Y5.FEED
FEED3: J2.FEED, Y2.S
FEED4: J3.FEED, Y3.FEED
FEED5: J4.FEED, R1.1
FEED6: J6.FEED, Y6.FEED
FEED7: J7.FEED, Y12.1
FEED8: J8.FEED, Y1.S
FEED9: J9.FEED, Y8.FEED
FEED10: J10.FEED, R2.1
FEED11: J11.FEED, Y10.FEED
FEED12: J12.FEED, Y11.FEED
FEED13: J13.FEED, Y18.1
FEED14: J14.FEED, Y13.S
FEED15: J15.FEED, Y14.FEED
FEED16: J16.FEED, R3.1
FEED17: J17.FEED, Y16.FEED
FEED18: J18.FEED, Y17.FEED
FEED19: J19.FEED, Y24.1
FEED20: J20.FEED, Y19.S
FEED21: J21.FEED, Y20.FEED
FEED22: J22.FEED, R4.1
FEED23: J23.FEED, Y22.FEED
FEED24: J24.FEED, Y23.FEED
GND: J1.1, J1.2, J2.1, J2.2, J3.1, J3.2, J4.1, J4.2, J5.1, J5.2, J6.1, J6.2, Y2.1, Y2.2, Y2.3, Y3.GND, Y4.1, Y4.2, Y4.3, Y6.GND, Y7.2, Y7.3
GND1: J7.1, J7.2, J8.1, J8.2, J9.1, J9.2, J10.1, J10.2, J11.1, J11.2, J12.1, J12.2, Y1.1, Y1.2, Y1.3, Y8.GND, Y9.1, Y9.2, Y9.3, Y11.GND, Y12.2, Y12.3
GND2: J13.1, J13.2, J14.1, J14.2, J15.1, J15.2, J16.1, J16.2, J17.1, J17.2, J18.1, J18.2, Y13.1, Y13.2, Y13.3, Y14.GND, Y15.1, Y15.2, Y15.3, Y17.GND, Y18.2, Y18.3
GND3: J19.1, J19.2, J20.1, J20.2, J21.1, J21.2, J22.1, J22.2, J23.1, J23.2, J24.1, J24.2, Y19.1, Y19.2, Y19.3, Y20.GND, Y21.1, Y21.2, Y21.3, Y23.GND, Y24.2, Y24.3
unnamed: R2.2, Y9.FEED
unnamed: R1.2, Y4.FEED
unnamed: R3.2, Y15.FEED
unnamed: R4.2, Y21.FEED

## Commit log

2019-02-04 File rename
    [GNSS_Chip_Antenna_Evaluation_Board.brd, GNSS_Chip_Antenna_Evaluation_Board.sch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]
2019-02-05 Add license, readme, ignore. Add logo. Add GNSS freq table to sch. Touch up sch.
    [GNSS_Chip_Antenna_Evaluation_Board.brd, GNSS_Chip_Antenna_Evaluation_Board.sch]
2019-02-08 Adding production panel
    [GNSS_Chip_Antenna_Evaluation_Board-Panel.GBL, GNSS_Chip_Antenna_Evaluation_Board-Panel.GBO, GNSS_Chip_Antenna_Evaluation_Board-Panel.GBS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]
2019-02-21 Removing lib. Adding test result images.
    [GNSS_Chip_Antenna_Evaluation_Board.brd, GNSS_Chip_Antenna_Evaluation_Board.sch]
2019-03-08 Pass review: Change silk. Add dims. Revise a few FPs.
    [GNSS_Chip_Antenna_Evaluation_Board.brd, GNSS_Chip_Antenna_Evaluation_Board.sch]
2019-03-12 Add schematic title. Bump fiducials. Move version #.
    [GNSS_Chip_Antenna_Evaluation_Board.brd, GNSS_Chip_Antenna_Evaluation_Board.sch]
2019-03-25 Corrected the polygon FP issue on the U.FL.
    [GNSS_Chip_Antenna_Evaluation_Board-Panel.GBL, GNSS_Chip_Antenna_Evaluation_Board-Panel.GBO, GNSS_Chip_Antenna_Evaluation_Board-Panel.GBS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]
2019-03-25 Removing old files.
    [GNSS_Chip_Antenna_Evaluation_Board.brd, GNSS_Chip_Antenna_Evaluation_Board.sch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]

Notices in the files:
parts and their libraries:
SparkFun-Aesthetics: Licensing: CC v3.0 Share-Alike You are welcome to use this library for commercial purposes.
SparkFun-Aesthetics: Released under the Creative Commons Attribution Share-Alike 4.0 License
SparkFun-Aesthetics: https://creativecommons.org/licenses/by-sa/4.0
